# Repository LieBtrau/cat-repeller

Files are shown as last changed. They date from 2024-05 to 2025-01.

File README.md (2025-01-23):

# cat-repeller
Detect cat with PIR sensor and scare them off using ultrasound.  Settings and control through Web Bluetooth

## Operation
* Solar panel used as light sensor to detect day/night.  
* PIR sensor detects motion.  

### LEDs
* During daylight, the white LEDs will be disabled because they have little effect and consume power.
* The red LED will signal the device is active using short blinks.

## Electronics
### CATPIR
PCB holding PIR-sensor and piezo buzzer.

* [CATPIR 1.0.0 : PCB source](https://365.altium.com/files/FE5699FE-DB18-49EB-B4F2-E8AD16447050)

## Firmware 
### Piezo control
* Down-chirp signal to scare off cats.  Due to tolerances not every piezo will resonate at the same frequency.  The down-chirp will cover a range of frequencies.  The down-chirp is used in alarm systems as well.  My personal opinion is that a down-chirp relates more to danger than an up-chirp or a constant tone.

https://randomnerdtutorials.com/esp32-web-bluetooth/
https://randomnerdtutorials.com/esp32-deep-sleep-arduino-ide-wake-up-sources/

https://microcontrollerslab.com/esp32-ble-server-gatt-service-battery-level-indication/
https://circuitdigest.com/microcontroller-projects/esp32-based-bluetooth-ibeacon

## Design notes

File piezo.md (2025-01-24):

# Acoustic Resonance (?)
1. Connect the piezo element directly to the output of the signal generator.
2. Set the signal generator to sine wave mode, no DC-offset.
3. Connect an oscilloscope to the signal generator output
3. Sweep the frequency range from 1kHz to 100kHz.
4. Watch the oscilloscope for a dip in the sine wave.

For the piezo elements of the Delta-Sport cat repeller, that frequency is 22kHz.

Is this the acoustic resonance?  When doing the same test with another piezo element, the frequency where the dip occurs was the loudest.

# Capacitance of the piezo elements
The capacitance of the Delta-Sport elements is around 115nF

# Parallel inductor
We need an inductor to form an parallel LC-resonant circuit at double the acoustic frequency.

$$
L = \frac{1}{(2*\pi*f)^2*C} = \frac{1}{(2*\pi*44k)^2*115n} = 114µH
$$

By trial and error, I tried several inductors to find the one that yielded the highest voltage across the piezo element.  The inductor that worked best was between 120µH and 150µH.

# Breadboard LC-resonant circuit
The circuit according to [EDN](https://www.edn.com/increase-piezoelectric-transducer-acoustic-output-with-a-simple-circuit/).  BS170 NMOS-transistor with 1ohm from Source to Ground.  The inductor consists of a series of two 56µH inductors. 

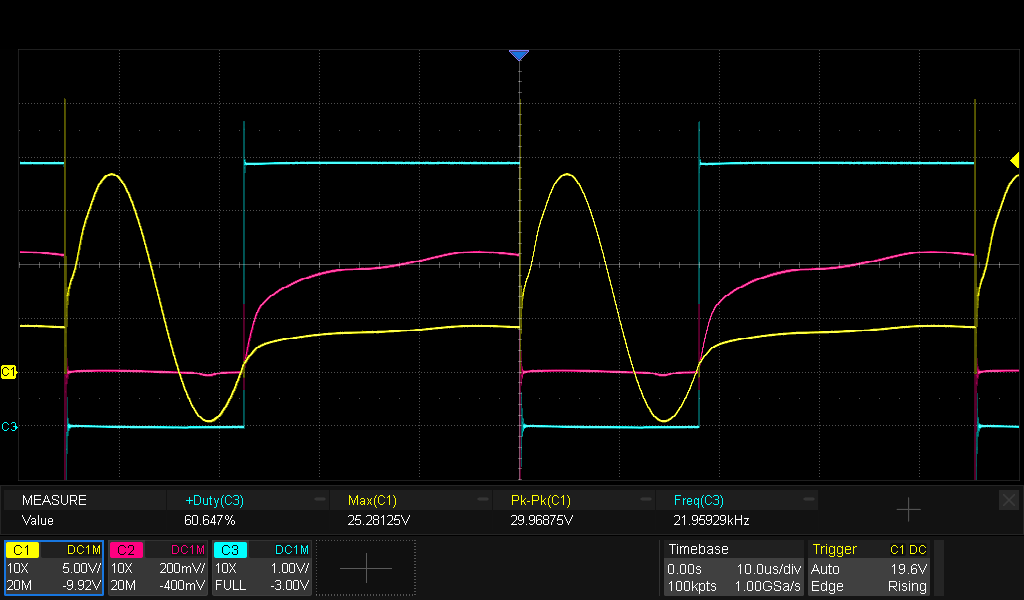
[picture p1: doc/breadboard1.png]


* Yellow trace : voltage at the anode of the 1N4148 diode
* Pink trace : voltage on the source of the BS170 NMOS-transistor
* Blue trace : voltage on the gate of the BS170 NMOS-transistor

To avoid current peaks, the duty cycle of the square wave should be between 60% and 70%.

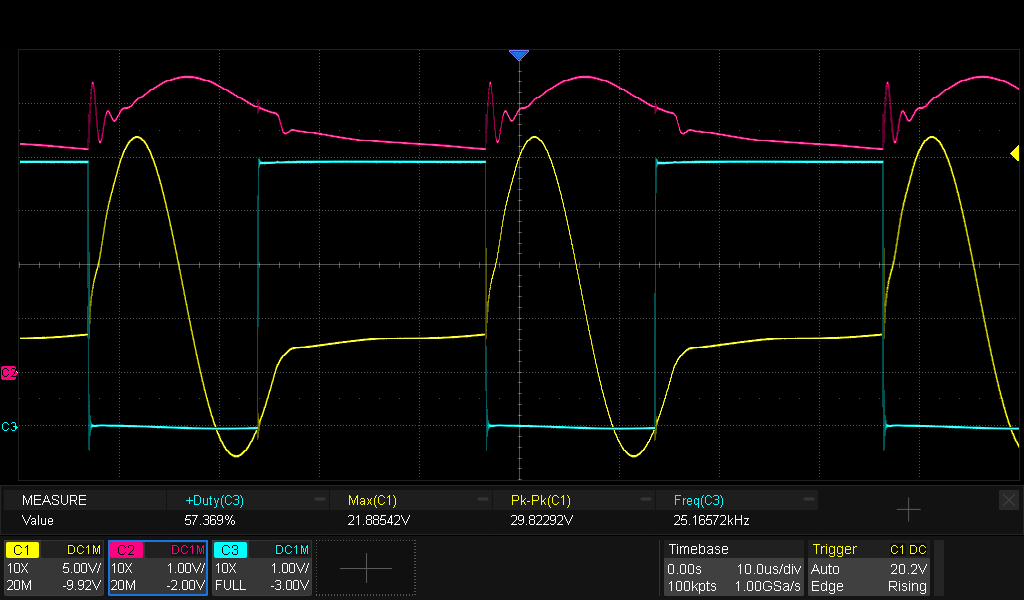
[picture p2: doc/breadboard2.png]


* Yellow trace : voltage at the anode of the 1N4148 diode
* Pink trace : voltage over a 1ohm resistor connected between +5V and the top of the inductor.
* Blue trace : voltage on the gate of the BS170 NMOS-transistor

There's about 1.5A peak to peak current through the inductor.

# Alternative circuit
Another method is to build a boost converter and then drive the piezo element with a square wave.  

# Hardware test of CATPIR1.0.0
* The supply voltage has been lowered to 2.5V to avoid the piezo element from breaking.  At 5V, the supply current is more than 1A (display on the power supply).  With 2.5V, the supply current is around 0.27A.

## Changes
* A03400 was not available, so I used an SI2308DS instead.  It's a 60V/2A NMOS-transistor.
* PMEG10020ELRX was not available, so I used a SDM2100S1F-7 diode instead.

## Duty cycle of the NMOS-transistor
The duty cycle of the square wave should be between 55% and 75%.  Closer to 55% is better.

## Output voltage
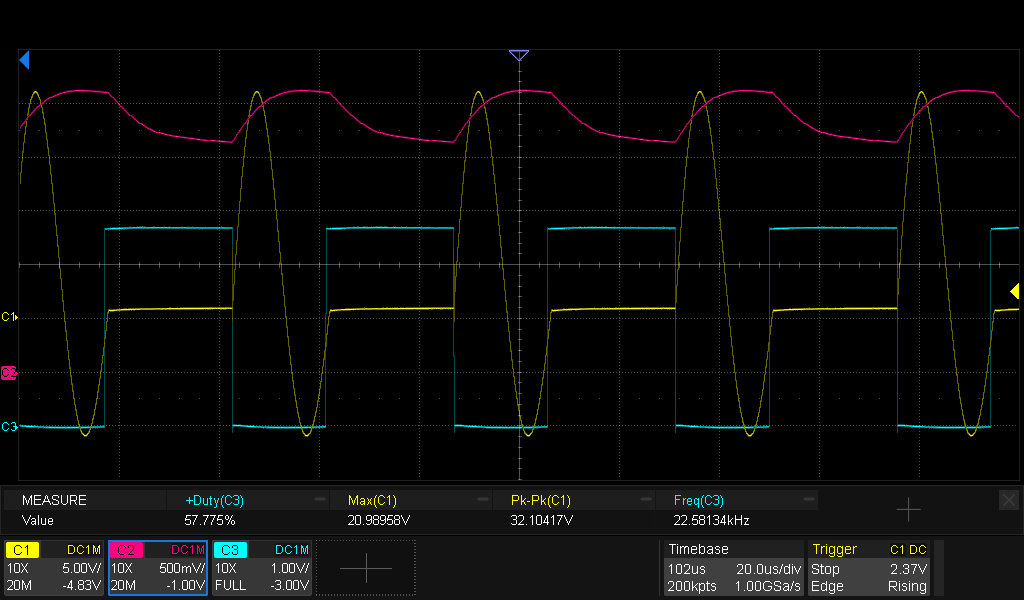
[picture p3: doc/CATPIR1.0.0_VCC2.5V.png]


* Yellow trace : voltage at the anode of the SOD123F diode
* Pink trace : voltage at VBAT
* Blue trace : voltage at the gate of Q1.

## Conclusion
* Peak-peak voltage at the anode of the diode is 32.2V, which is much more than the original 9.9Vpp in the Delta-Sport design.
* The ferrite bead causes a considerable loss.  We better replace it with a wire.  There doesn't seem to be any short current spikes.

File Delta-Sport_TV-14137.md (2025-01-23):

# Specification
## Power Supply
* ICR18650-1300FY, protected Li-Ion cell : 1300mAh, 100㏀ thermistor.  Unfortunately it's not a 10㏀ thermistor, which would have been a more standard value for connection to a battery charger.
* Solar panel : 5.5V open circuit, 10mA short circuit
* LDO : 2.5V output, which is used as VCC for MCU and PIR-sensors

## LED
JST-PH clone connector :
1. Cathode red LED (probably has a resistor)
2. Cathode White LEDs
3. Anode red LED
4. Anode White LEDs

There are 6 white LEDs in parallel, they are bright enough at 50mA.  The forward voltage is around 3.3V then.

## Piezo
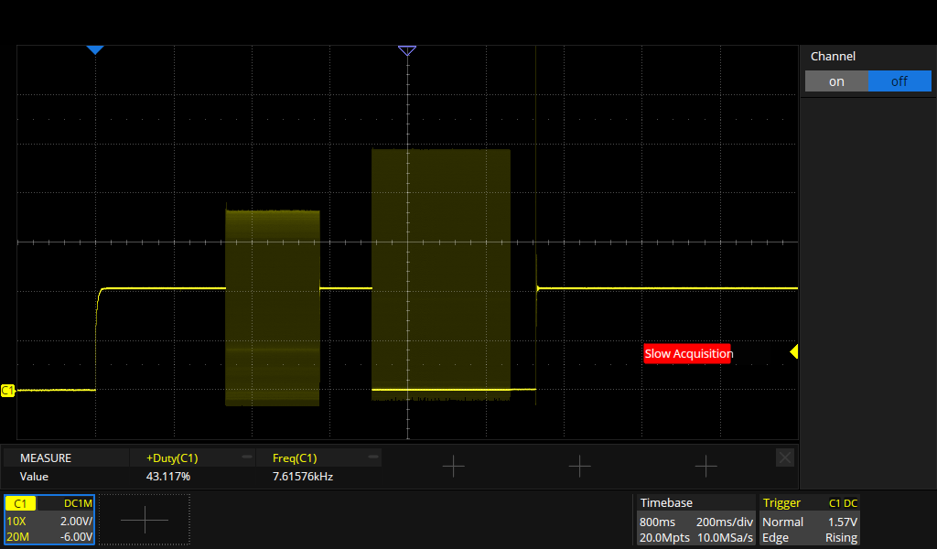
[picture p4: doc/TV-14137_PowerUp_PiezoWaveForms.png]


At power up: 240ms, 8kHz waveform, followed by 355ms of 24.8kHz

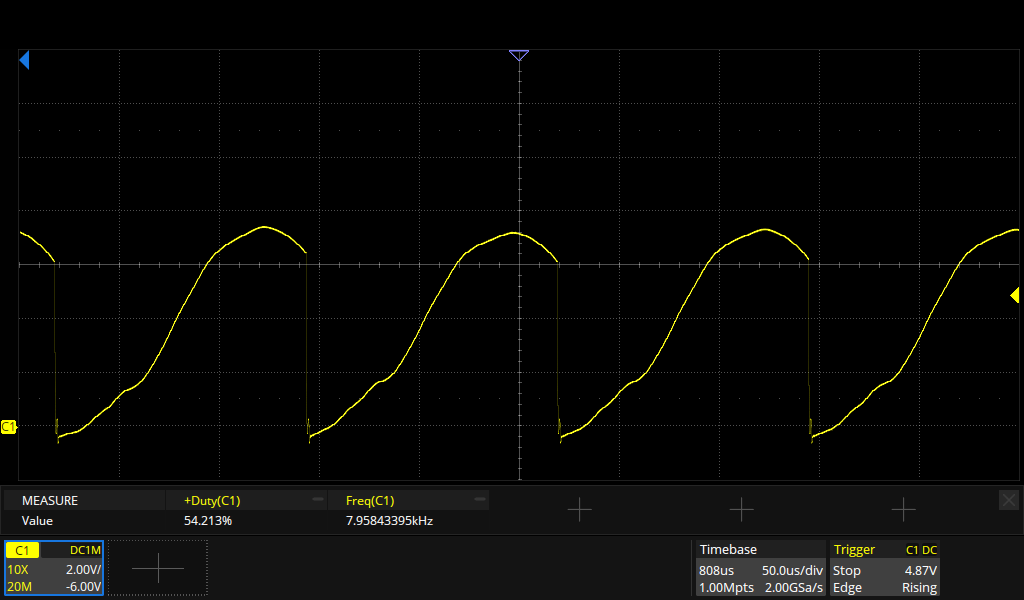
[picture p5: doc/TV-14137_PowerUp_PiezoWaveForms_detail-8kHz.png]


8kHz waveform = 7.91Vpp

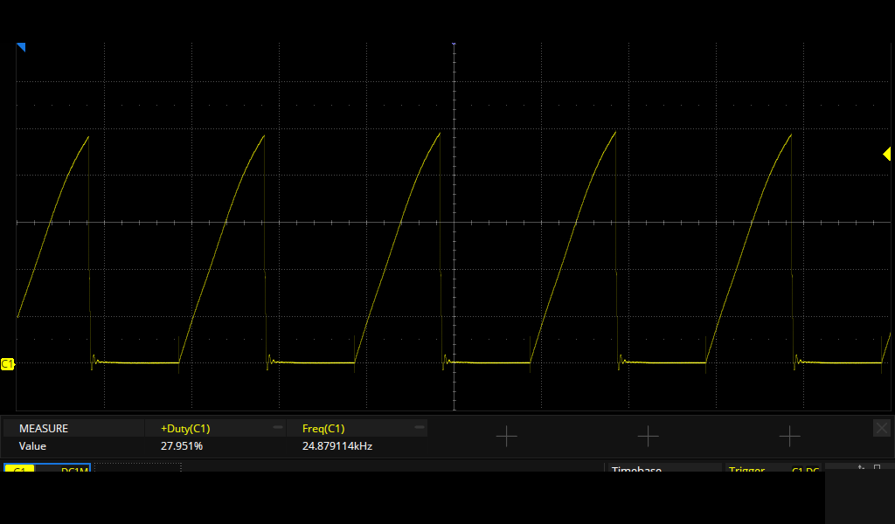
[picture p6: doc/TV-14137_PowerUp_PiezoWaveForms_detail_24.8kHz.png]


24.8kHz waveform = 9.9Vpp

## PIR sensor
At startup, the PIR-sensor data shows some pulses.  Later on, it continuously outputs a 62% duty cycle square wave at 2.5V.  I have no idea how this ASchip D210AX works.  It seems to use a serial one-wire protocol to transfer its ADC-value.  The [datasheet](./doc/ASChip_D210AX.pdf) doesn't provide any info about the protocol.

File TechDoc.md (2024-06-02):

# Features
## Required
* +3 months battery life with 1500mAh LiPo battery

## Nice to have
* Bluetooth Low Energy (BLE) communication for settings and control
* Bluetooth connection should be established within 5 seconds

# Current consumption
t = 3 months = 90 days = 2160 hours
Q = 1000mAh (just to have some margin)
I = Q / t = 1000mAh / 2160h = 0.46mA

So, the current consumption should be less than 0.46mA.

# MCU Selection
## ESP32-C3
### Sleep modes
#### Option 1: Deep sleep
The device goes to deep sleep and regularly wakes up to advertise BLE.  The problem is that after deep sleep, the device needs to reboot.  Reboot takes a few seconds during which 10s of mA are being drawn.  It's not an option to reboot every 10s, that just consumes too much current.

#### Option 2: Light sleep
The device goes to light sleep and wakes up to advertise BLE.  The device doesn't need to reboot after light sleep.  The current consumption is higher than deep sleep, but it's still low enough for the battery life requirement.

Unfortunately, I haven't found any example code for light sleep with BLE advertising.  To get the most out of it (lowest current consumption), esp-idf instead of Arduino needs to be used.
An [external 32.768kHz crystal is needed for light sleep](https://docs.espressif.com/projects/espressif-esp-faq/en/latest/software-framework/ble-bt.html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).  The [Bluetooth radio can wakeup the CPU from light sleep](https://docs.espressif.com/projects/esp-idf/en/v5.0/esp32/api-reference/system/sleep_modes.html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).

It will be a lot of work for this nice-to-have feature.

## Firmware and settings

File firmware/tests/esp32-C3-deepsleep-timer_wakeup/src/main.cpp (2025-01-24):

/*
Simple Deep Sleep with Timer Wake Up
=====================================
ESP32 offers a deep sleep mode for effective power
saving as power is an important factor for IoT
applications. In this mode CPUs, most of the RAM,
and all the digital peripherals which are clocked
from APB_CLK are powered off. The only parts of
the chip which can still be powered on are:
RTC controller, RTC peripherals ,and RTC memories

This code displays the most basic deep sleep with
a timer to wake it up and how to store data in
RTC memory to use it over reboots

This code is under Public Domain License.

Author:
Pranav Cherukupalli <cherukupallip@gmail.com>
*/

#include <Arduino.h>

#define uS_TO_S_FACTOR 1000000  /* Conversion factor for micro seconds to seconds */
#define TIME_TO_SLEEP  5        /* Time ESP32 will go to sleep (in seconds) */
static const char *TAG = "main";

RTC_DATA_ATTR int bootCount = 0;

/*
Method to print the reason by which ESP32
has been awaken from sleep
*/
void print_wakeup_reason(){
  esp_sleep_wakeup_cause_t wakeup_reason;

  wakeup_reason = esp_sleep_get_wakeup_cause();

  switch(wakeup_reason)
  {
    case ESP_SLEEP_WAKEUP_EXT0 : Serial.println("Wakeup caused by external signal using RTC_IO"); break;
    case ESP_SLEEP_WAKEUP_EXT1 : Serial.println("Wakeup caused by external signal using RTC_CNTL"); break;
    case ESP_SLEEP_WAKEUP_TIMER : Serial.println("Wakeup caused by timer"); break;
    case ESP_SLEEP_WAKEUP_TOUCHPAD : Serial.println("Wakeup caused by touchpad"); break;
    case ESP_SLEEP_WAKEUP_ULP : Serial.println("Wakeup caused by ULP program"); break;
    default : Serial.printf("Wakeup was not caused by deep sleep: %d\n",wakeup_reason); break;
  }
}

void setup(){
  delay(2000); //Take some time to open up the Serial Monitor
  ESP_LOGI(TAG, "Build %s, %s %s\r\n", AUTO_VERSION, __DATE__, __TIME__);

  //Increment boot number and print it every reboot
  ++bootCount;
  ESP_LOGI(TAG, "Boot number: %d", bootCount);

  //Print the wakeup reason for ESP32
  print_wakeup_reason();

  /*
  First we configure the wake up source
  We set our ESP32 to wake up every 5 seconds
  */
  esp_sleep_enable_timer_wakeup(TIME_TO_SLEEP * uS_TO_S_FACTOR);
  ESP_LOGI(TAG, "Setup ESP32 to sleep for every %d Seconds", TIME_TO_SLEEP);

  /*
  Next we decide what all peripherals to shut down/keep on
  By default, ESP32 will automatically power down the peripherals
  not needed by the wakeup source, but if you want to be a poweruser
  this is for you. Read in detail at the API docs
  http://esp-idf.readthedocs.io/en/latest/api-reference/system/deep_sleep.html
  Left the line commented as an example of how to configure peripherals.
  The line below turns off all RTC peripherals in deep sleep.
  */
  //esp_deep_sleep_pd_config(ESP_PD_DOMAIN_RTC_PERIPH, ESP_PD_OPTION_OFF);
  //Serial.println("Configured all RTC Peripherals to be powered down in sleep");

  /*
  Now that we have setup a wake cause and if needed setup the
  peripherals state in deep sleep, we can now start going to
  deep sleep.
  In the case that no wake up sources were provided but deep
  sleep was started, it will sleep forever unless hardware
  reset occurs.
  */
  ESP_LOGI(TAG, "Entering deep sleep");
  delay(1000);
  Serial.flush(); 
  esp_deep_sleep_start();
  ESP_LOGI(TAG, "This will never be printed");
}

void loop(){
  //This is not going to be called
}

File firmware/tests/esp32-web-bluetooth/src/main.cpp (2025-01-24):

#include <Arduino.h>
#include <BLEDevice.h>
#include <BLEServer.h>
#include <BLEUtils.h>
#include <BLE2902.h>
#include "AsyncDelay.h"

static const char *TAG = "main";
/*
  Rui Santos
  Complete project details at https://RandomNerdTutorials.com/esp32-web-bluetooth/

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
  The above copyright notice and this permission notice shall be included in all
  copies or substantial portions of the Software.
*/

// See the following for generating UUIDs:
// https://www.uuidgenerator.net/

#define SERVICE_UUID "19b10000-e8f2-537e-4f6c-d104768a1214"
#define SENSOR_CHARACTERISTIC_UUID "19b10001-e8f2-537e-4f6c-d104768a1214"
#define LED_CHARACTERISTIC_UUID "19b10002-e8f2-537e-4f6c-d104768a1214"

BLEServer *pServer = NULL;
BLECharacteristic *pSensorCharacteristic = NULL;
BLECharacteristic *pLedCharacteristic = NULL;
static bool deviceConnected = false;
static uint32_t value = 0;
static AsyncDelay samplingInterval;
static AsyncDelay advertizingInterval;

static void setup_ble();
static void start_advertising();

const int ledPin = 2; // Use the appropriate GPIO pin for your setup

void setup()
{
	delay(2000); // Wait for the VCP to connect

	ESP_LOGI(TAG, "Build %s, %s %s\r\n", AUTO_VERSION, __DATE__, __TIME__);
	setup_ble();
}

class MyServerCallbacks : public BLEServerCallbacks
{
	void onConnect(BLEServer *pServer)
	{
		deviceConnected = true;
	};

	void onDisconnect(BLEServer *pServer)
	{
		deviceConnected = false;
	}
};

class MyCharacteristicCallbacks : public BLECharacteristicCallbacks
{
	void onWrite(BLECharacteristic *pLedCharacteristic)
	{
		std::string value = pLedCharacteristic->getValue();
		if (value.length() > 0)
		{
			Serial.print("Characteristic event, written: ");
			Serial.println(static_cast<int>(value[0])); // Print the integer value

			int receivedValue = static_cast<int>(value[0]);
			if (receivedValue == 1)
			{
				digitalWrite(ledPin, HIGH);
			}
			else
			{
				digitalWrite(ledPin, LOW);
			}
		}
	}
};

void setup_ble()
{
	pinMode(ledPin, OUTPUT);

	// Create the BLE Device
	BLEDevice::init("ESP32");

	// Create the BLE Server
	pServer = BLEDevice::createServer();
	pServer->setCallbacks(new MyServerCallbacks());

	// Create the BLE Service
	BLEService *pService = pServer->createService(SERVICE_UUID);

	// Create a BLE Characteristic
	pSensorCharacteristic = pService->createCharacteristic(
		SENSOR_CHARACTERISTIC_UUID,
		BLECharacteristic::PROPERTY_READ |
			BLECharacteristic::PROPERTY_WRITE |
			BLECharacteristic::PROPERTY_NOTIFY |
			BLECharacteristic::PROPERTY_INDICATE);

	// Create the ON button Characteristic
	pLedCharacteristic = pService->createCharacteristic(
		LED_CHARACTERISTIC_UUID,
		BLECharacteristic::PROPERTY_WRITE);

	// Register the callback for the ON button characteristic
	pLedCharacteristic->setCallbacks(new MyCharacteristicCallbacks());

	// https://www.bluetooth.com/specifications/gatt/viewer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
	// Create a BLE Descriptor
	pSensorCharacteristic->addDescriptor(new BLE2902());
	pLedCharacteristic->addDescriptor(new BLE2902());

	// Start the service
	pService->start();

	// Start advertising
	BLEAdvertising *pAdvertising = BLEDevice::getAdvertising();
	pAdvertising->addServiceUUID(SERVICE_UUID);
	pAdvertising->setScanResponse(false);
	pAdvertising->setMinPreferred(0x0); // set value to 0x00 to not advertise this parameter
	start_advertising();
	ESP_LOGI(TAG, "Waiting a client connection to notify...");
	BLEDevice::
}

typedef enum connection_state
{
	DISCONNECTED,
	CONNECTED
} connection_state_t;

void loop()
{
	static connection_state_t connection_state = DISCONNECTED;

	switch (connection_state)
	{
	case DISCONNECTED:
		if (advertizingInterval.isExpired())
		{
			esp_sleep_enable_timer_wakeup(7e6);
			esp_light_sleep_start();
			//esp_deep_sleep_start();
			start_advertising();
		}
		if (deviceConnected)
		{
			connection_state = CONNECTED;
			ESP_LOGI(TAG, "Device Connected");
			samplingInterval.start(3000, AsyncDelay::MILLIS);
		}
		break;
	case CONNECTED:
		if (deviceConnected)
		{
			if (samplingInterval.isExpired())
			{
				samplingInterval.repeat();
				// notify changed value
				pSensorCharacteristic->setValue(String(value).c_str());
				pSensorCharacteristic->notify();
				ESP_LOGI(TAG, "New value notified: %d", value);
				value++;
			}
		}
		else
		{
			ESP_LOGI(TAG, "Device disconnected.");
			delay(500); // give the bluetooth stack the chance to get things ready
			start_advertising();
			connection_state = DISCONNECTED;
		}
		break;
	}
}

void start_advertising()
{
	BLEDevice::startAdvertising();
	delay(100);
	BLEDevice::stopAdvertising();
	advertizingInterval.start(1000, AsyncDelay::MILLIS);
}

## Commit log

2024-06-02 Adding simulation for piezo driver
2024-06-04 Add piezo circuit
2024-06-06 Add inductor current measurement
2024-06-09 Layout ongoing
    [PCB_Project.PrjPcb]
2024-06-09 Adding BoMDoc
    [CATPIR.PcbDoc, CATPIR.PrjPcb, pir-piezo.SchDoc]
2024-06-12 Fix DRC-errors Add output jobs
    [CATPIR.PcbDoc, CATPIR.PrjPcb]
2024-06-12 Update Draftsman document, so that it shows the correct GIT version
    [CATPIR.PrjPcb]
2025-01-24 Adding hardware design
    [Controller.PrjPcb, PCB.PcbDoc, main.SchDoc]
2025-01-24 Add replacement diode type
2025-01-24 Add PCB files
    [CATPIR.PcbDoc, CATPIR.PrjPcb, pir-piezo.SchDoc]
